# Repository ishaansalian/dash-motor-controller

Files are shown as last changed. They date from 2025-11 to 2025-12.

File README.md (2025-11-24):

# 48V BLDC Motor Controller for Dash Robot
Motor control PCB for the Dash humanoid robot project.

## Specs
- 48V nominal input
- 3-phase BLDC motor control
- DRV8323 gate driver
- CAN bus communication
- Based on Ben Katz + mjbots Moteus designs

## Status
🚧 In development - schematic complete, layout in progress

## Hardware
- MCU: STM32F446
- Gate Driver: DRV8323RSRGZT
- MOSFETs: BSC030N08NS5 (80V, 3mΩ)
- Encoder: MA732GQ-Z
- CAN: MCP2542FD

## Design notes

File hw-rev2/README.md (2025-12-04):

# Dash48V
48v version motor controller board

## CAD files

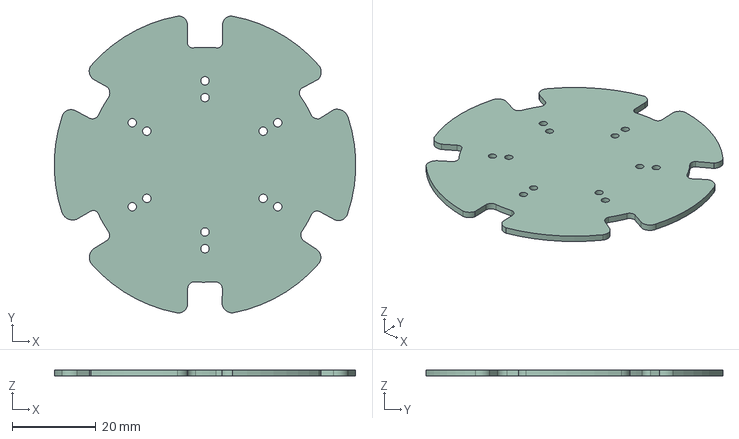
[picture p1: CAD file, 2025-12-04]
hw-rev2/DashMotor48V.step
71.8 x 70.7 x 1.51 mm

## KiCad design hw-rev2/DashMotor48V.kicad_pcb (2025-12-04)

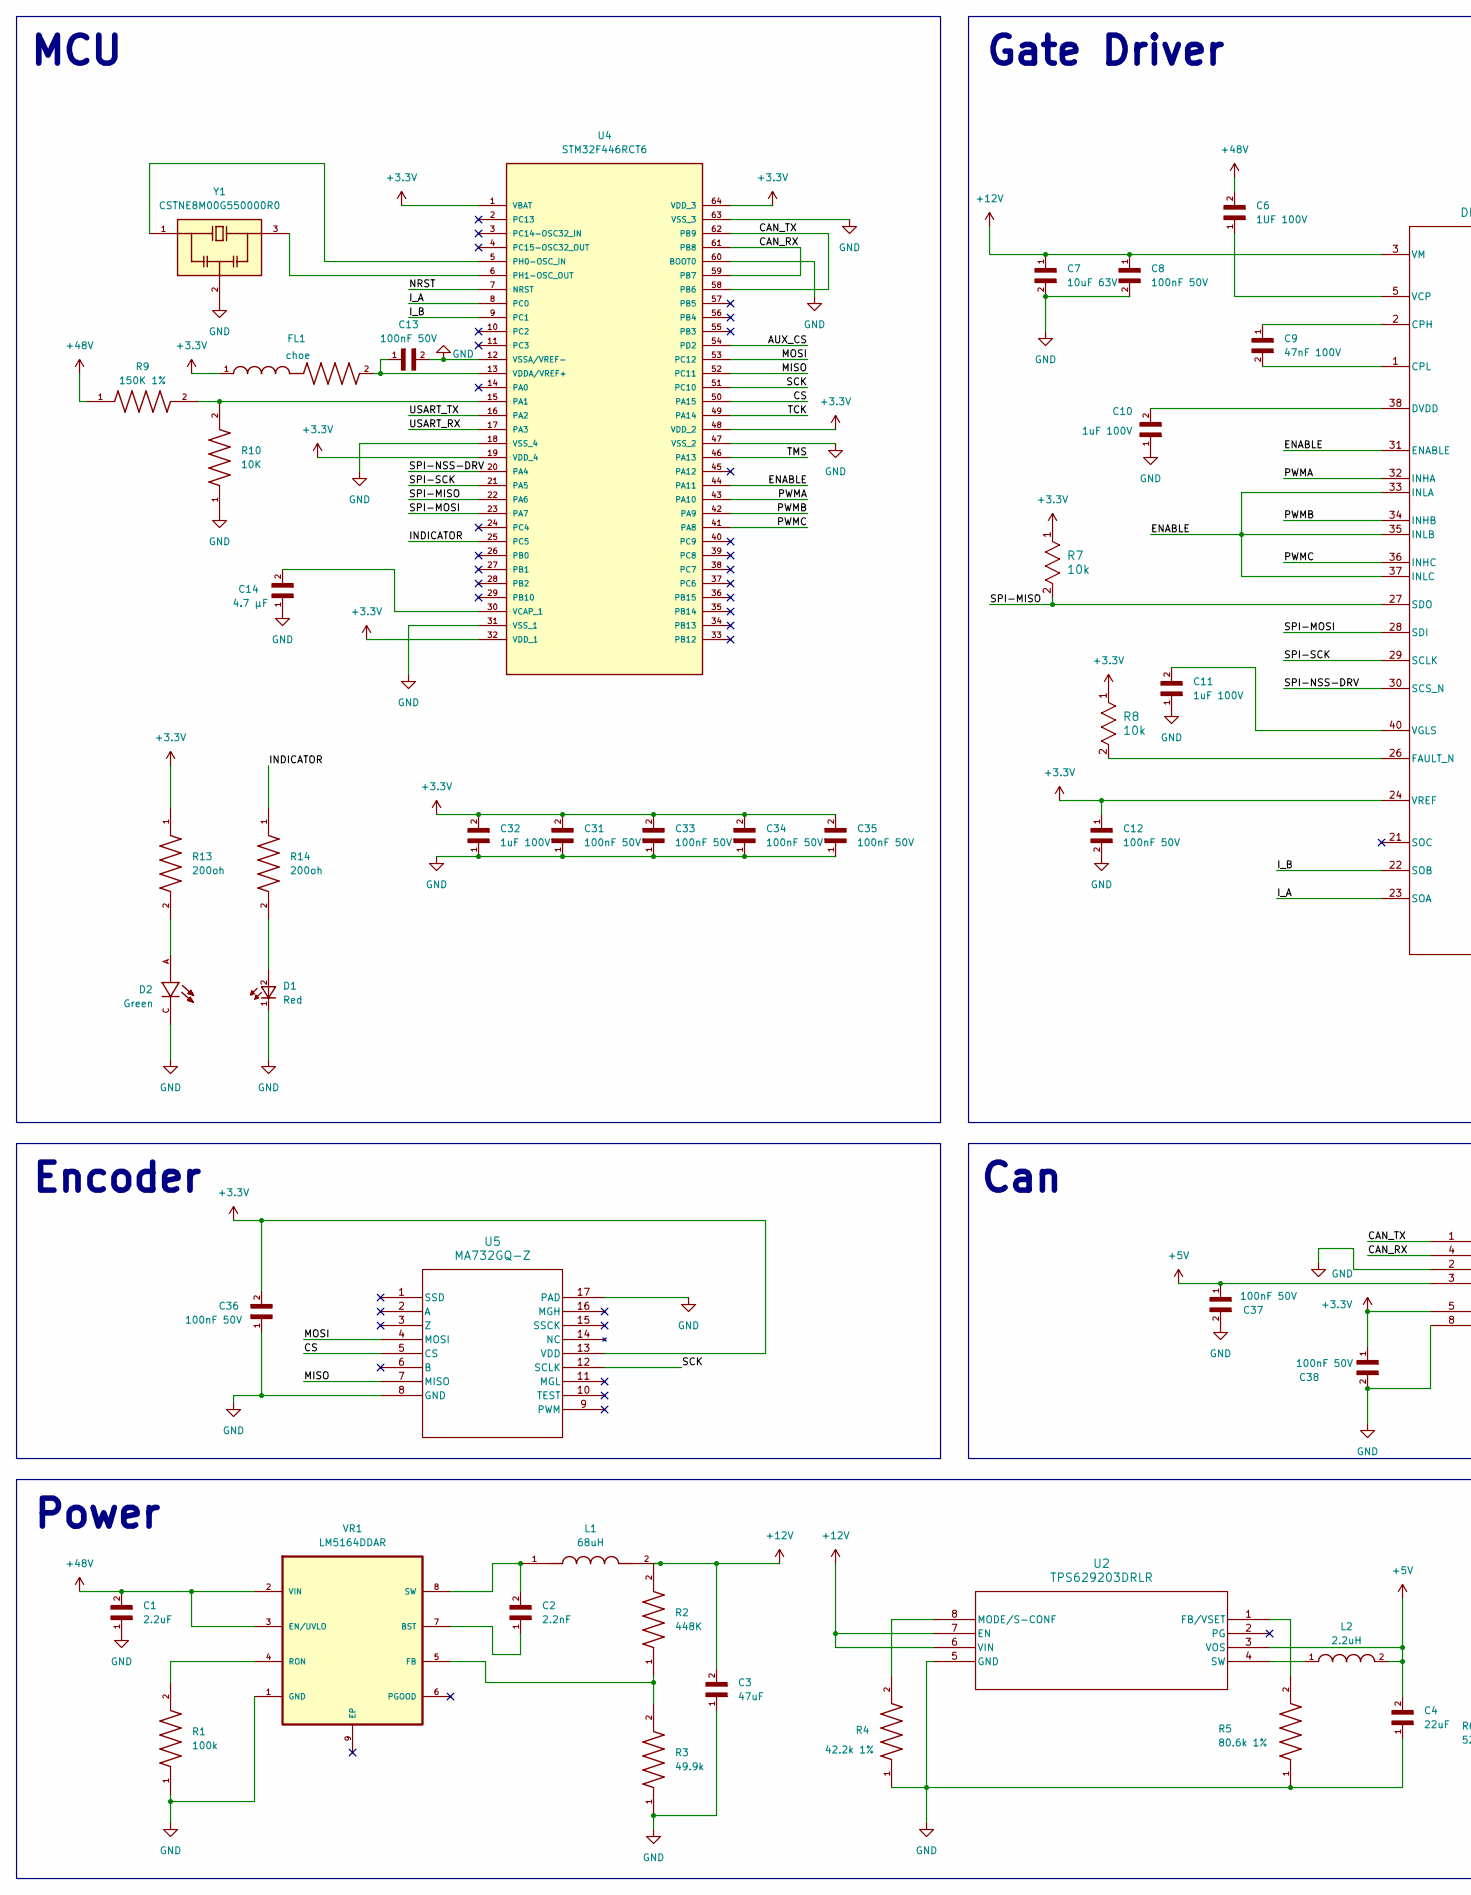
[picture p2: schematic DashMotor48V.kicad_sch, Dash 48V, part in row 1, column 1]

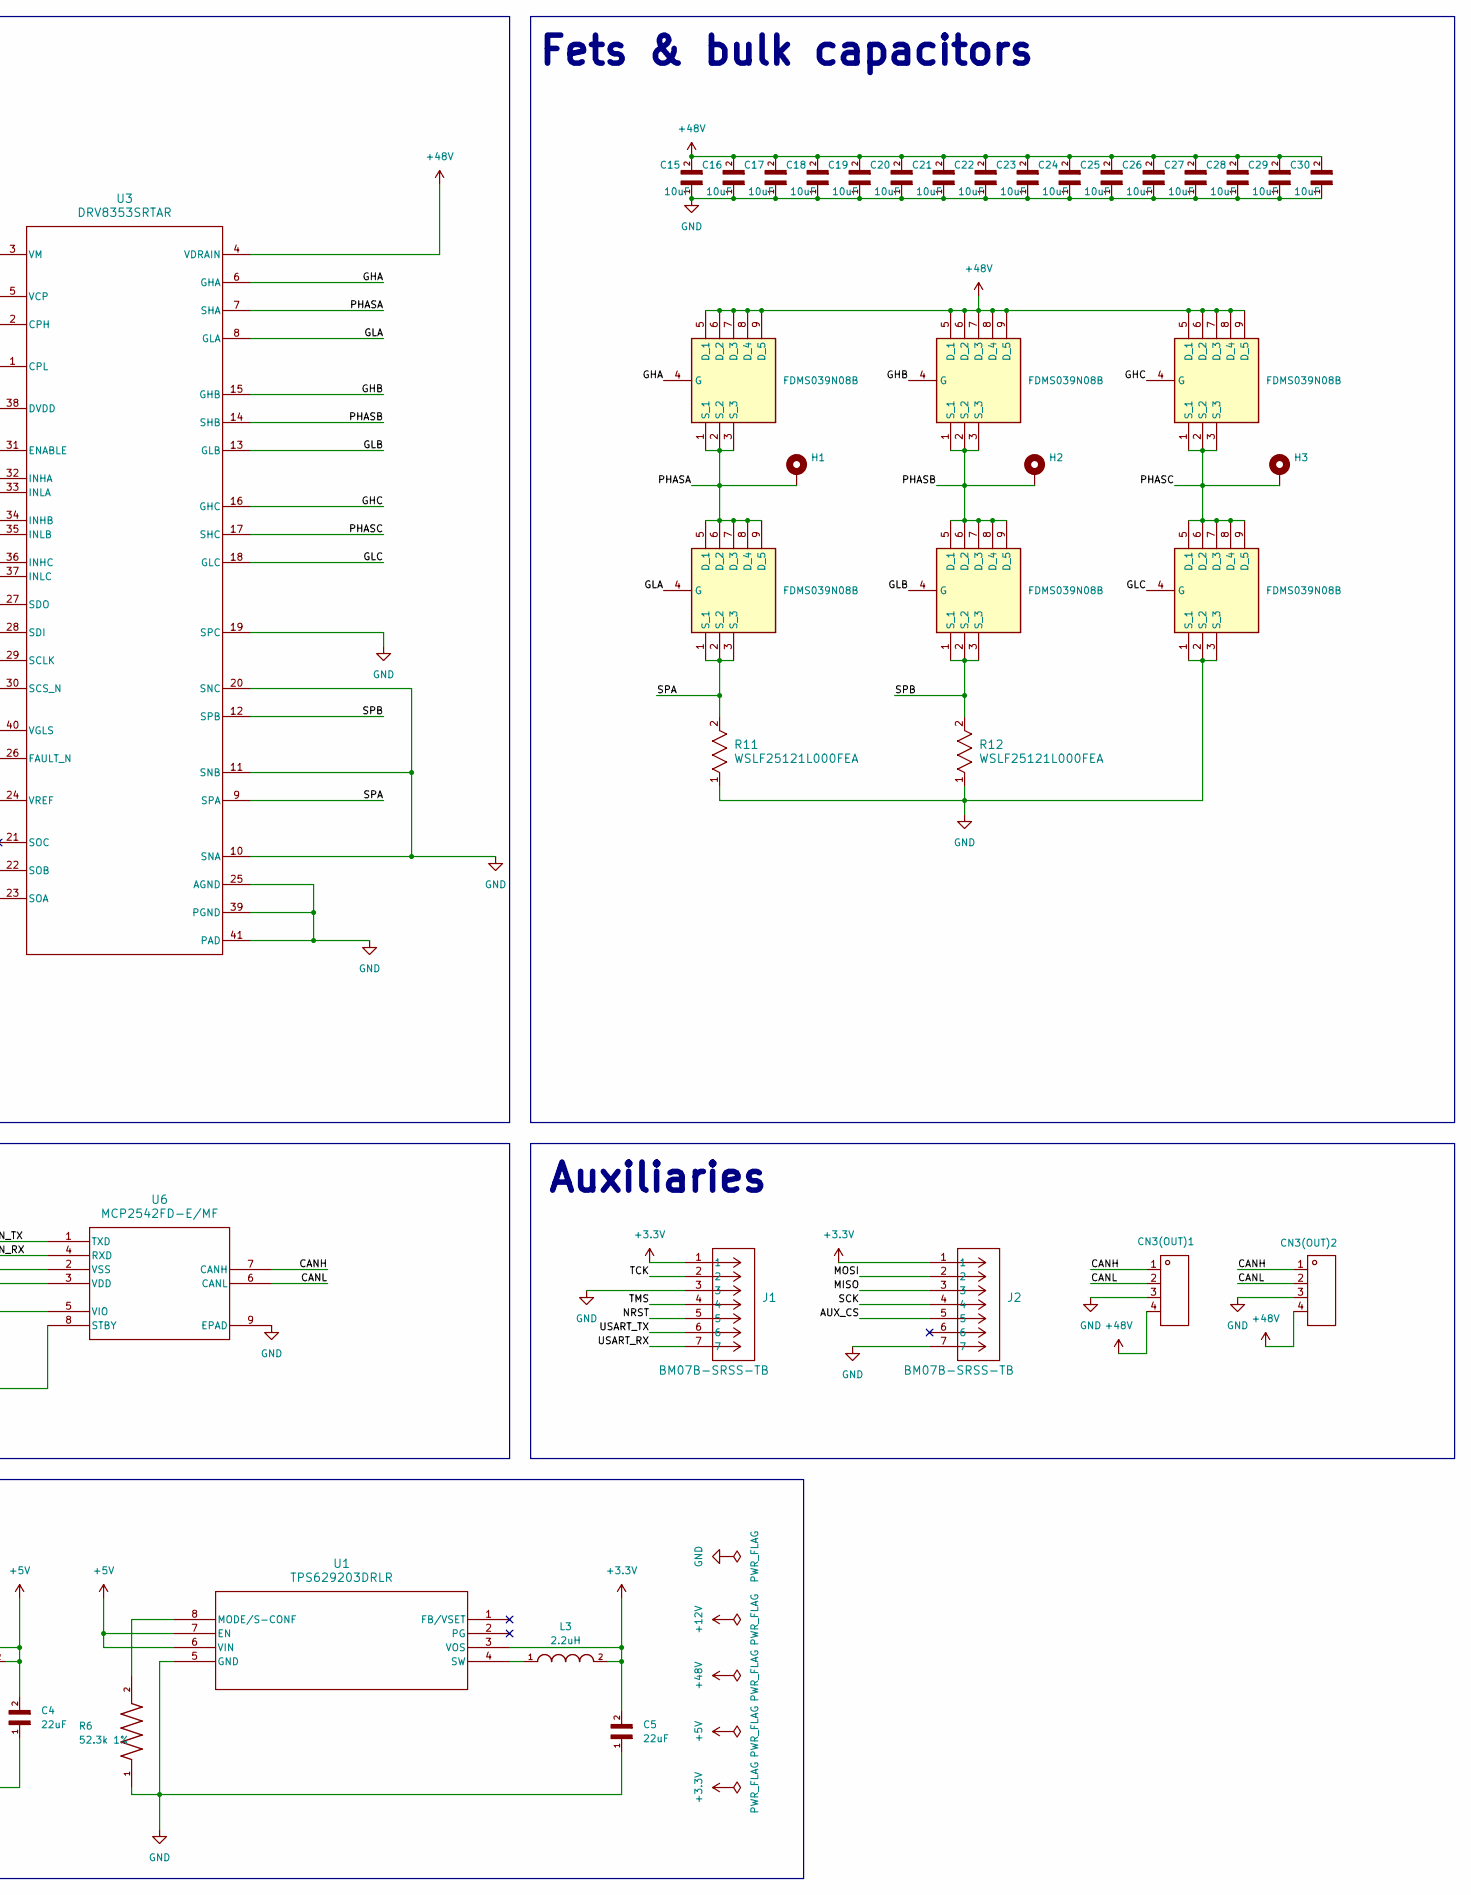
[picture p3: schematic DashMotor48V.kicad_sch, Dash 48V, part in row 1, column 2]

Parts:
C1: 2.2uF; CL31B225KCHSNNE
C2: 2.2nF; CL10B222KB8NNNC
C3: 47uF; GRM31CR61E476ME44L
C4, C5: 22uF; GRM32ER71E226KE15L
C6: 1UF 100V; CL31B105KCHNNNE
C7: 10uF 63V; GRM32ER71J106KA12L
C8, C12, C13, C31, C33, C34, C35, C36, C37, C38: 100nF 50V; CC0603JRX7R9BB104
C9: 47nF 100V; CC0603KRX7R0BB473
C10, C11, C32: 1uF 100V; CL31B105KCHNNNE
C14: 4.7 µF; GRM155R60J475ME87D
C15, C16, C17, C18, C19, C20, C21, C22, C23, C24, C25, C26, C27, C28, C29, C30: 10uF; GRM32EC72A106KE05L
CN3(OUT)1, CN3(OUT)2: XT30(2+2)PB-M.G.B; Manufacturer Part XT30(2+2)PB-M.G.B
D1: Red; LTST_C191KRKT
D2: Green; LTST-C190KGKT
FL1: choe; BLM18AG601SN1D
H1, H2, H3: MountingHole_Pad; MountingHole_2.2mm_M2_Pad
J1, J2: BM07B-SRSS-TB
L1: 68uH; VLS5045EX_680M; PARTREV N/A
L2, L3: 2.2uH; DFE252012PD_2R2M_P2
Q1, Q2, Q3, Q4, Q5, Q6: FDMS039N08B; Manufacturer_Part_Number FDMS039N08B; Mouser Part Number 512-FDMS039N08B
R1: 100k; RC0805FR_07100KL
R2: 448K; RT0603BRD07448KL
R3: 49.9k; RT0603BRD0749K9L
R4: 42.2k 1%; RC0402FR_0742K2L
R5: 80.6k 1%; RC0402FR_0780K6L
R6: 52.3k 1%; RC0402FR_0752K3L
R7, R8: 10k; RC0402FR_0710KL
R9: 150K 1%; RC0402FR_07150KL
R10: 10K; RT0402DRE0710KL
R11, R12: WSLF25121L000FEA
R13, R14: 200oh; RC0402JR-07200RL
U1, U2: TPS629203DRLR
U3: DRV8353SRTAR
U4: STM32F446RCT6
U5: MA732GQ-Z
U6: MCP2542FD-E/MF; MCP2542FD_E_MF
VR1: LM5164DDAR
Y1: CSTNE8M00G550000R0

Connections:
+3.3V: C5.2, C12.1, C31.2, C32.2, C33.2, C34.2, C35.2, C36.2, C38.1, FL1.1, J1.1, J2.1, L3.2, R7.1, R8.1, R13.1, U1.3 (VOS), U3.24 (VREF), U4.1 (VBAT), U4.19 (VDD_4), U4.32 (VDD_1), U4.48 (VDD_2), U4.64 (VDD_3), U5.13 (VDD), U6.5 (VIO)
+5V: C4.2, C37.1, L2.2, U1.6 (VIN), U1.7 (EN), U2.3 (VOS), U6.3 (VDD)
+12V: C3.2, C7.1, C8.1, L1.2, R2.2, U2.6 (VIN), U2.7 (EN), U3.3 (VM)
+48V: C1.2, C6.2, C15.2, C16.2, C17.2, C18.2, C19.2, C20.2, C21.2, C22.2, C23.2, C24.2, C25.2, C26.2, C27.2, C28.2, C29.2, C30.2, CN3(OUT)1.4, CN3(OUT)2.4, Q1.5 (D_1), Q1.6 (D_2), Q1.7 (D_3), Q1.8 (D_4), Q1.9 (D_5), Q3.5 (D_1), Q3.6 (D_2), Q3.7 (D_3), Q3.8 (D_4), Q3.9 (D_5), Q5.5 (D_1), Q5.6 (D_2), Q5.7 (D_3), Q5.8 (D_4), Q5.9 (D_5), R9.1, U3.4 (VDRAIN), VR1.2 (VIN), VR1.3 (EN/UVLO)
/AUX_CS: J2.5, U4.54 (PD2)
/CANH: CN3(OUT)1.1, CN3(OUT)2.1, U6.7 (CANH)
/CANL: CN3(OUT)1.2, CN3(OUT)2.2, U6.6 (CANL)
/CAN_RX: U4.59 (PB7), U4.61 (PB8), U6.4 (RXD)
/CAN_TX: U4.58 (PB6), U4.62 (PB9), U6.1 (TXD)
/CS: U4.50 (PA15), U5.5 (CS)
/ENABLE: U3.31 (ENABLE), U3.33 (INLA), U3.35 (INLB), U3.37 (INLC), U4.44 (PA11)
/GHA: Q1.4 (G), U3.6 (GHA)
/GHB: Q3.4 (G), U3.15 (GHB)
/GHC: Q5.4 (G), U3.16 (GHC)
/GLA: Q2.4 (G), U3.8 (GLA)
/GLB: Q4.4 (G), U3.13 (GLB)
/GLC: Q6.4 (G), U3.18 (GLC)
/INDICATOR: R14.1, U4.25 (PC5)
/I_A: U3.23 (SOA), U4.8 (PC0)
/I_B: U3.22 (SOB), U4.9 (PC1)
/MISO: J2.3, U4.52 (PC11), U5.7 (MISO)
/MOSI: J2.2, U4.53 (PC12), U5.4 (MOSI)
/NRST: J1.5, U4.7 (NRST)
/PHASA: H1.1, Q1.1 (S_1), Q1.2 (S_2), Q1.3 (S_3), Q2.5 (D_1), Q2.6 (D_2), Q2.7 (D_3), Q2.8 (D_4), Q2.9 (D_5), U3.7 (SHA)
/PHASB: H2.1, Q3.1 (S_1), Q3.2 (S_2), Q3.3 (S_3), Q4.5 (D_1), Q4.6 (D_2), Q4.7 (D_3), Q4.8 (D_4), Q4.9 (D_5), U3.14 (SHB)
/PHASC: H3.1, Q5.1 (S_1), Q5.2 (S_2), Q5.3 (S_3), Q6.5 (D_1), Q6.6 (D_2), Q6.7 (D_3), Q6.8 (D_4), Q6.9 (D_5), U3.17 (SHC)
/PWMA: U3.32 (INHA), U4.43 (PA10)
/PWMB: U3.34 (INHB), U4.42 (PA9)
/PWMC: U3.36 (INHC), U4.41 (PA8)
/SCK: J2.4, U4.51 (PC10), U5.12 (SCLK)
/SPA: Q2.1 (S_1), Q2.2 (S_2), Q2.3 (S_3), R11.2, U3.9 (SPA)
/SPB: Q4.1 (S_1), Q4.2 (S_2), Q4.3 (S_3), R12.2, U3.12 (SPB)
/SPI-MISO: R7.2, U3.27 (SDO), U4.22 (PA6)
/SPI-MOSI: U3.28 (SDI), U4.23 (PA7)
/SPI-NSS-DRV: U3.30 (SCS_N), U4.20 (PA4)
/SPI-SCK: U3.29 (SCLK), U4.21 (PA5)
/TCK: J1.2, U4.49 (PA14)
/TMS: J1.4, U4.46 (PA13)
/USART_RX: J1.7, U4.17 (PA3)
/USART_TX: J1.6, U4.16 (PA2)
GND: C1.1, C3.1, C4.1, C5.1, C7.2, C8.2, C10.1, C11.1, C12.2, C13.2, C14.1, C15.1, C16.1, C17.1, C18.1, C19.1, C20.1, C21.1, C22.1, C23.1, C24.1, C25.1, C26.1, C27.1, C28.1, C29.1, C30.1, C31.1, C32.1, C33.1, C34.1, C35.1, C36.1, C37.2, C38.2, CN3(OUT)1.3, CN3(OUT)2.3, D1.1, D2.C, J1.3, J2.7, Q6.1 (S_1), Q6.2 (S_2), Q6.3 (S_3), R1.1, R3.1, R4.1, R5.1, R6.1, R10.1, R11.1, R12.1, U1.5 (GND), U2.5 (GND), U3.10 (SNA), U3.11 (SNB), U3.19 (SPC), U3.20 (SNC), U3.25 (AGND), U3.39 (PGND), U3.41 (PAD), U4.12 (VSSA/VREF-), U4.18 (VSS_4), U4.31 (VSS_1), U4.47 (VSS_2), U4.60 (BOOT0), U4.63 (VSS_3), U5.8 (GND), U5.17 (PAD), U6.2 (VSS), U6.8 (STBY), U6.9 (EPAD), VR1.1 (GND), Y1.2
unnamed: D1.2, R14.2
unnamed: D2.A, R13.2
unnamed: R6.2, U1.8 (MODE/S-CONF)
unnamed: L3.1, U1.4 (SW)
unnamed: R5.2, U2.1 (FB/VSET)
unnamed: R4.2, U2.8 (MODE/S-CONF)
unnamed: L2.1, U2.4 (SW)
unnamed: C9.1, U3.2 (CPH)
unnamed: C9.2, U3.1 (CPL)
unnamed: C10.2, U3.38 (DVDD)
unnamed: R8.2, U3.26 (FAULT_N)
unnamed: C6.1, U3.5 (VCP)
unnamed: C11.2, U3.40 (VGLS)
unnamed: R9.2, R10.2, U4.15 (PA1)
unnamed: U4.5 (PH0-OSC_IN), Y1.1
unnamed: U4.6 (PH1-OSC_OUT), Y1.3
unnamed: C14.2, U4.30 (VCAP_1)
unnamed: C13.1, FL1.2, U4.13 (VDDA/VREF+)
unnamed: C2.1, VR1.7 (BST)
unnamed: R2.1, R3.2, VR1.5 (FB)
unnamed: R1.2, VR1.4 (RON)
unnamed: C2.2, L1.1, VR1.8 (SW)

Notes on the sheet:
MCU
Auxiliaries
Gate Driver
Can
Encoder
Fets & bulk capacitors
Power

Board: 4 copper layers, 79 parts (22 on the bottom side), 63 nets, no tracks yet.

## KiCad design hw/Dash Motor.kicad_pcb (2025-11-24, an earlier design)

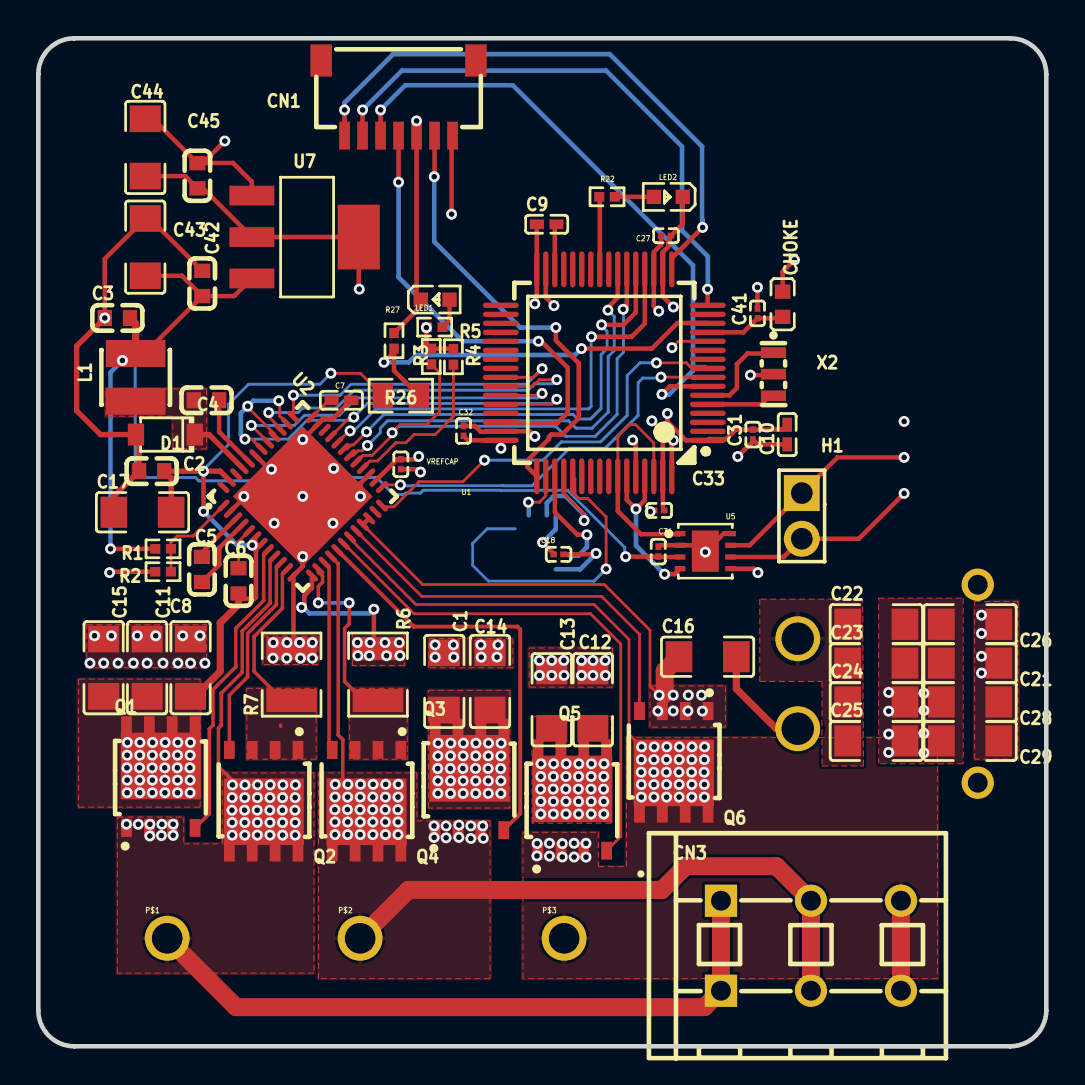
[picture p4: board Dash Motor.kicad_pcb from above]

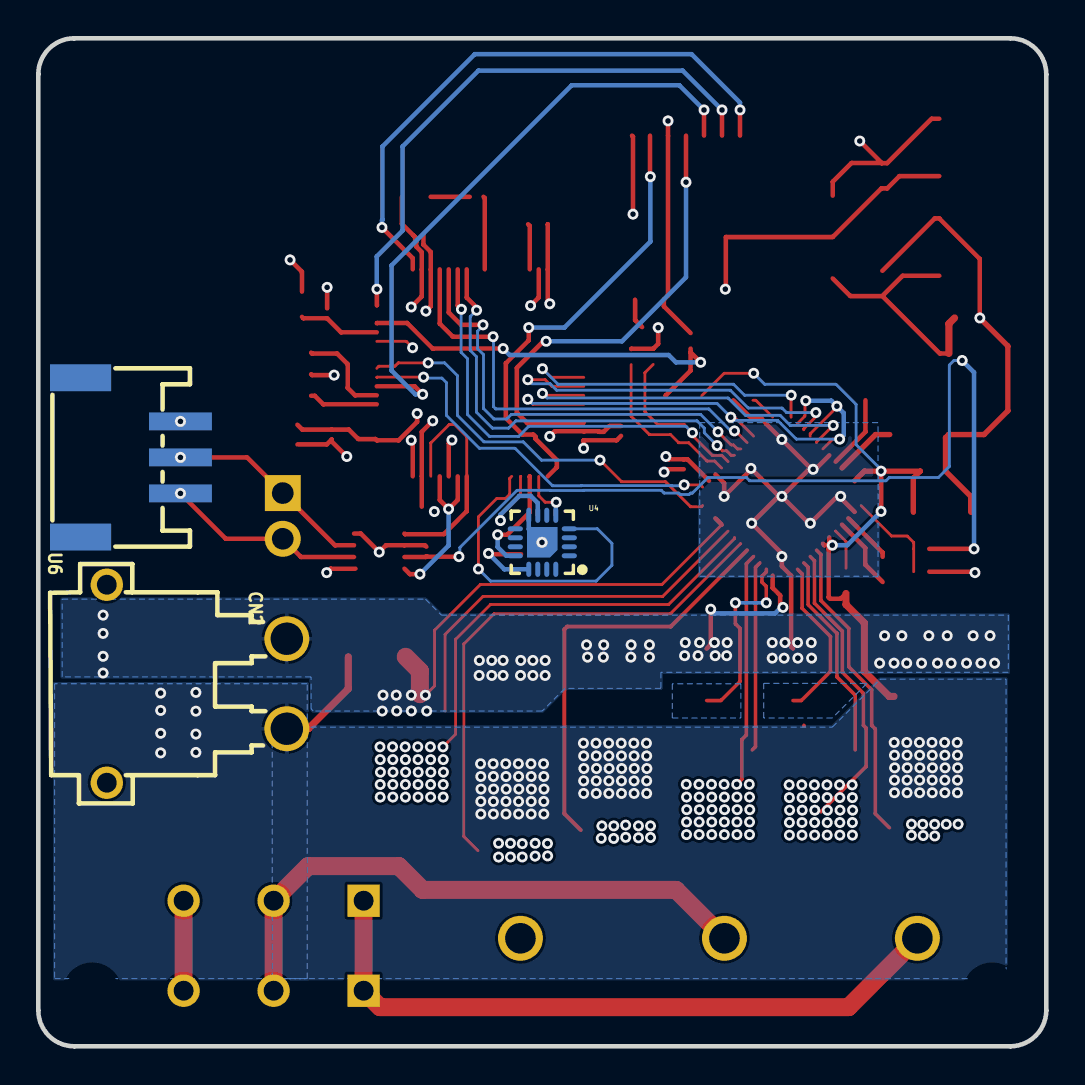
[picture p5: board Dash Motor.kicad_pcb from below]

Board: 4 copper layers, 56.0 x 56.0 mm, 72 parts (3 on the bottom side), 54 nets.

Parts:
C1, C8, C11, C12, C13, C14, C15, C16, C17, C21, C22, C23, C24, C25, C26, C28, C29, C43, C44: C1206
C2, C3, C4, C5, C6, C42, C45: C0603
C7, C9, C10: C0402
C18, C27, C31, C32, C33, C34, C41: C0201
CHOKE: L0603
CN1: CONN-SMD_SM07B-SRSS-TB
CN2: CONN-TH_XT30PW-M
CN3: CONN-TH_XY119A-5.0-3P
D1: SOD-123_L2.7-W1.6-LS3.7-RD
H1: HDR-TH_2P-P2.54-V-M
L1: IND-SMD_L3.0-W3.0
LED1, LED2: LED0603-RD
P$1, P$2, P$3: HOLEHOLE
Q1, Q2, Q3, Q4, Q5, Q6: SOP-8_L5.0-W5.0-P1.27-LS6.0_TPH4R008NH-L1Q
R1, R2, R3, R4, R5, R22, R27: R0402
R6, R7: R1210
R26: R0805
U1: LQFP-64_L10.0-W10.0-P0.50-LS12.0-BL
U2: VQFN-48_L7.0-W7.0-P0.50-BL-EP5.5
U4: QFN-16_L3.0-W3.0-P0.50-TL-EP1.7
U5: DFN-8_L3.0-W3.0-P0.65-BL-EP-1
U6: CONN-SMD_S3B-PH-SM4-TB-LF-SN
U7: SOT-223-3_L6.5-W3.4-P2.30-LS7.0-BR
VREFCAP: C0201
X2: OSC-SMD_3P-L3.2-W1.3-P1.20-L

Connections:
3V3: C9.1, C10.2, C18.2, C27.2, C31.2, C32.2, C33.1, C44.1, C45.1, CHOKE.1, CN1.1, R3.2, R4.2, R5.2, U1.1, U1.19, U1.32, U1.48, U1.64, U2.26, U4.13, U5.5, U7.2, U7.4, VREFCAP.2
5V: C3.2, C34.2, C42.2, C43.2, L1.1, R1.2, U5.3, U7.3
24V: C1.2, C2.2, C6.2, C8.2, C11.2, C12.2, C13.2, C14.2, C15.2, C16.2, C17.2, C21.2, C22.2, C23.2, C24.2, C25.2, C26.2, C28.2, C29.2, CN2.2, Q1.5, Q1.6, Q1.7, Q1.8, Q1.9, Q3.5, Q3.6, Q3.7, Q3.8, Q3.9, Q5.5, Q5.6, Q5.7, Q5.8, Q5.9, R26.1, U2.6, U2.7, U2.47
$1N749: U1.5, X2.3
$1N755: U1.6, X2.1
$1N1053: C41.1, CHOKE.2, U1.13
$1N1928: R26.2, R27.2, U1.14
$1N2202: C9.2, U1.30
$1N2494: LED1.2, R5.1
$1N2499: LED2.2, R22.1
$1N13638: R4.1, U2.28
$1N13862: C6.1, U2.5
$1N14164: C4.2, U2.44
$1N14240: R1.1, R2.2, U2.1
$1N14304: C5.2, U2.4
$1N14310: C5.1, U2.3
$1N14320: C7.2, U2.36
CANH: H1.1, U5.7, U6.2
CANL: H1.2, U5.6, U6.3
CAN_RX: U1.59, U1.61, U5.4
CAN_TX: U1.58, U1.62, U5.1
CS: U1.50, U4.5
ENABLE: U1.44, U2.33, U2.38, U2.40, U2.42
GHA: Q1.4, U2.8
GHB: Q3.4, U2.17
GHC: Q5.4, U2.18
GLA: Q2.4, U2.10
GLB: Q4.4, U2.15
GLC: Q6.4, U2.20
GND: C1.1, C2.1, C3.1, C7.1, C8.1, C10.1, C11.1, C12.1, C13.1, C14.1, C15.1, C16.1, C17.1, C18.1, C21.1, C22.1, C23.1, C24.1, C25.1, C26.1, C27.1, C28.1, C29.1, C31.1, C32.1, C33.2, C34.1, C41.2, C42.1, C43.1, C44.2, C45.2, CN1.3, CN2.1, D1.2, LED1.1, LED2.1, Q6.1, Q6.2, Q6.3, R2.1, R6.1, R7.2, R27.1, U1.12, U1.18, U1.31, U1.47, U1.60, U1.63, U2.2, U2.12, U2.13, U2.21, U2.22, U2.27, U2.35, U2.43, U2.49, U4.8, U4.17, U5.2, U5.8, U5.9, U6.1, U7.1, VREFCAP.1, X2.2
INDICATOR: R22.2, U1.25
I_A: U1.8, U2.25
I_B: U1.9, U2.24
MISO: U1.52, U4.7
MOSI: U1.53, U4.4
NRST: CN1.5, U1.7
PHASA: CN3.1, P$1.1, Q1.1, Q1.2, Q1.3, Q2.5, Q2.6, Q2.7, Q2.8, Q2.9, U2.9
PHASB: CN3.2, P$2.1, Q3.1, Q3.2, Q3.3, Q4.5, Q4.6, Q4.7, Q4.8, Q4.9, U2.16
PHASC: CN3.3, P$3.1, Q5.1, Q5.2, Q5.3, Q6.5, Q6.6, Q6.7, Q6.8, Q6.9, U2.19
PWMA: U1.43, U2.41
PWMB: U1.42, U2.39
PWMC: U1.41, U2.37
SCK: U1.51, U4.12
SPA: Q2.1, Q2.2, Q2.3, R7.1, U2.11
SPB: Q4.1, Q4.2, Q4.3, R6.2, U2.14
SPI-MISO: R3.1, U1.22, U2.29
SPI-MOSI: U1.23, U2.30
SPI-NSS-DRV: U1.20, U2.32
SPI-SCK: U1.21, U2.31
SW: C4.1, D1.1, L1.2, U2.45
TCK: CN1.2, U1.49
TMS: CN1.4, U1.46
USART_RX: CN1.7, U1.17
USART_TX: CN1.6, U1.16
